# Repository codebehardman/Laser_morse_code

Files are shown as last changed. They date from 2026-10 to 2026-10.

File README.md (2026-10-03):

# Laser Morse Code Transceiver

Firmware for laser transceiver: two identical units that talk
to each other in Morse code over a visible laser beam, without any
radio emissions (so they can be used inside the National Radio Quiet Zone).

Both units run the **same firmware** on an **ESP32-WROOM-32 DevKit**, and
each one can both send and receive. The ESP32's Wi-Fi and Bluetooth are never
switched on by this firmware, so the board does not transmit radio.

(Earlier versions targeted the NUCLEO-F401RE and STM32F103C8T6; see the git
history, e.g. commit `f61c9a8`, if you need them.)

## Modes

When a unit powers up, the on-board LED gives a short blip every half
second while it waits. The **first key press** chooses the mode:

| Press | Mode | LED confirmation |
|---|---|---|
| Tap (< 1 s) | **Morse code** | one long flash |
| Hold ≥ 1 s  | **Serial terminal** | two long flashes (they start while you're still holding, so let go then) |

The serial monitor shows the chosen mode (`===== Mode: ... =====`). Press
**EN** to reset and choose again.

The mode stays until you press reset or cut the power. Set both units to the
same mode.

### Morse code mode
- **Send:** the key turns the laser on while pressed (hand keying, around
  12 words per minute). Text typed in the serial console is keyed out
  automatically at a faster 20 WPM (`/wpm` changes it). Morse is slow:
  roughly 0.6 s per letter at 20 WPM, so the console shows how long each
  message will take.
- Typed messages start with the Morse start-of-message signal `-.-.-` (KA).
  It lets the receiver lock onto the faster typed speed before the first
  letter, and it is not shown as text.
- **Receive:** the LED lights while the laser hits the phototransistor, and
  the pulses are decoded to text in the serial console. The receiver adapts
  to the sender's speed: it compares short and long marks to find the
  dot/dash cutoff, and after a pause it goes back to hand-keying speed.
- Holding the key for more than 1.5 s keeps the laser on for aiming. The
  receiver ignores holds that long, so aiming never shows up as text.

### Serial terminal mode
A text link between two PCs. Type a line and press **Enter**: the whole line
is sent over the laser and appears in the other unit's terminal as
`RX< ...`. It works in both directions at once.
- Each line travels as one frame (start marker, text, CRC-8 checksum, end
  marker). The receiver shows a line only if it arrived intact, and prints
  `[message corrupted - ask to resend]` otherwise.
- The laser link runs at **300 baud, 8 data bits, even parity, 1 stop bit**
  (about 27 characters per second). The design document specifies 9600 baud,
  but the phototransistor with its 100 kΩ pull-up is too slow for that (see
  Hardware notes). A dedicated task
  on the ESP32's second core sends and receives the bits, sampling the
  sensor 8 times per bit with a 3-sample majority vote.
- Backspace works while typing. Commands in this mode:
  - `/baud <n>` changes the link speed on the fly (set the **same** on both
    units).
  - `/rxdebug on|off` shows every received byte in hex, plus error counts.
  - `/level` and `/threshold` work here too. Everything else needs Morse mode.
- Holding the key keeps the laser on for aiming. The other unit sees this as
  a line break and prints nothing.
- The LED flashes when data arrives.

## Repository layout

```
platformio.ini            build environments (firmware + PC unit tests)
include/board_config.hpp  pin assignments and tunable constants
src/
  main.cpp                setup()/loop(): mode selection, then runs the mode
  modes/
    mode_select.{hpp,cpp}   power-up key press: short = Morse, long = serial
    morse_mode.{hpp,cpp}    Morse code mode
    serial_mode.{hpp,cpp}   serial terminal mode
  commands.{hpp,cpp}      serial console commands (/help, /test, /wpm, ...)
  diagnostics.{hpp,cpp}   hardware tests: laser, sensor, button, link
  console.{hpp,cpp}       serial console over the board's USB port
  device.hpp              references to all modules, shared by commands/tests
  drivers/                laser, phototransistor, button, status LED drivers,
                          laser_uart: serial link over the laser (core-0 task)
lib/morse/src/            hardware-independent Morse code library
  morse_code.{hpp,cpp}        ITU alphabet: A-Z, 0-9, punctuation
  morse_transmitter.{hpp,cpp} text -> laser on/off timing (non-blocking)
  morse_decoder.{hpp,cpp}     light timing -> text, adapts to the sender's speed
lib/optical_uart/src/     hardware-independent 8E1 software UART + line framing
test/                     unit tests for both libraries, run on your PC
```

## Wiring

| Part | ESP32 pin | Notes |
|---|---|---|
| Laser (via NPN transistor Q1) | **GPIO 25** | high = laser on |
| Phototransistor + 100 kΩ pull-up | **GPIO 26** | read with the ADC. **Pull-up to 3V3, never 5 V** |
| Key button to GND | **GPIO 27** | internal pull-up |
| Status LED | GPIO 2 (on board) | |
| Laser supply (R1 + laser diode) | **VIN / 5V** | USB 5 V while plugged in |
| Pull-up supply | **3V3** | |
| USB | on-board connector | power, serial console and flashing |

```
ESP32 DevKit
  VIN  ──[100Ω R1]──▶|── laser diode ── Q1 collector
  GPIO25 ──[~1kΩ]──────────────────────── Q1 base   (Q1 emitter → GND)
  3V3  ──[100kΩ]──┬── GPIO26
                  └── phototransistor collector   (emitter → GND)
  GPIO27 ──[button]── GND
```

ESP32 pins are 3.3 V only. Avoid GPIO 0, 2, 12 and 15 (they affect booting)
for external parts. To use different pins, add `-D LMC_PIN_...=` flags in
`platformio.ini`.

## Light threshold (ambient light)

The phototransistor is read with the ADC: **0 = very bright, 4095 = dark**. A
reading below the **threshold** counts as "laser detected". Ambient light
also lowers the reading, so a bright room needs a lower threshold than a
dark one.

**In the code**, set the room type in `include/board_config.hpp`:

```cpp
constexpr Lighting kLighting = Lighting::Dark;   // or Lighting::Bright
constexpr uint16_t kThresholdDarkRoom = 2000;
constexpr uint16_t kThresholdBrightRoom = 700;
```

**At runtime** (both modes, lost on reset):

| Command | Does |
|---|---|
| `/level` | shows the live reading for 5 s, with a bar and LASER/dark |
| `/threshold` | shows the current threshold and reading |
| `/threshold 1500` | sets it to 1500 |
| `/threshold dark` / `bright` | uses the preset from the config |
| `/threshold auto` | measures the room (other laser off), then the other unit's laser (hold its button), and sets the threshold halfway between |

Once you've found a value that works, put it in `board_config.hpp` so it
survives a reset.

## Flashing

Plug the ESP32 into the computer and run:

```sh
pio run -e esp32 -t upload
pio device monitor
```

Or in VS Code: PlatformIO sidebar → **esp32** → **Upload**, then
**Monitor**. The board shows up as `/dev/cu.usbserial-*` on macOS (`COMx` on
Windows). Close any serial monitor on that port first. If the upload stops
at "Connecting...", hold the board's **BOOT** button until the upload starts.
If it fails with "serial noise or corruption", lower `upload_speed` in
`platformio.ini` (e.g. to 115200).

Flash both units the same way.

## Using the serial console

Open the board's USB serial port in any terminal at **115200 baud**. Opening
the port restarts the board, so you'll see the mode prompt. The first line
shows the firmware build time (`firmware build 202610022245` =
2026-10-02 22:45), so you can check both units run the same version. In Morse mode,
each line you type is sent as Morse code when you press Enter. Received text
shows up as `RX< ...`.

```
/help               list commands
/status             settings, receiver state, decoder speed estimate
/wpm <n>            transmit speed, 5-40 words per minute (default 20)
/aim on|off         hold the laser on to align the units
/stop               abort the current transmission
/table              print the Morse alphabet
/level, /threshold  light sensor (see "Light threshold"; also in serial mode)
```

## Hardware tests

### Console tests (Morse mode)

| Command | What it checks |
|---|---|
| `/test laser`  | Blinks the laser 5 times. If you reflect the beam back with a mirror, it also counts the pulses at its own sensor |
| `/test sensor` | Prints every light/dark change for 10 s with timings and ADC levels. Use it to check aim and ambient-light interference |
| `/test button` | Prints key presses for 10 s |
| `/test all` | All of the above |
| `/test edge` then `/test tx 200 1` | **Receiver speed.** Run `/test edge` on the receiving unit, then `/test tx 200 1` on the other (200 pulses of 1 ms). Reports in microseconds how much the phototransistor stretches the pulses, and the highest link speed it can handle |
| `/test rx` then `/test tx` | **Link test across two units.** Run `/test rx` on the receiving unit first, then `/test tx` on the sending unit. The sender transmits 100 pulses of 20 ms. The receiver reports how many arrived and their widths, and gives PASS if the error rate is ≤ 10% (the design requirement) |

The link test is the quick way to run the distance (Test 2, 30 m) and
interference (Test 3, lamp at 1 m) checks from the design document.

## Unit tests (no hardware needed)

```sh
pio test -e native
```

- **Morse:** the alphabet tables, the transmitter's exact timing, and
  transmitter → decoder loopback, including speed mismatch, ±20% human timing
  jitter, switching between typed and hand-keyed speeds, the start prosign,
  aim holds and unknown patterns.
- **Serial link:** frame layout, all 256 byte values, any sampling phase,
  ±3% clock mismatch, detection of a flipped bit, glitches, and a held-on
  laser.
- **Line framing:** CRC, round trips, and that damaged or partial messages
  are always reported, never shown wrong or dropped silently.

## Morse timing

Standard ITU timing based on a unit of `1200 / WPM` ms: dot = 1 unit,
dash = 3, gap between elements = 1, between letters = 3, between words = 7.
The decoder estimates the sender's unit from the incoming marks, so people
keying at different speeds are decoded without any setup. Undecodable
patterns appear as `*`.

## Hardware notes

- **Laser brightness.** The laser circuit is designed for 5 V. Take it from
  the ESP32's VIN/5V pin, which carries USB 5 V while plugged in. From 3.3 V
  the laser gets only about a third of its current; if you must use 3.3 V,
  change R1 from 100 Ω to about 33 Ω (check the laser's datasheet first).
- **Phototransistor pull-up: sensitivity vs. speed.** A larger pull-up is
  more sensitive but slower to return high after the light goes off. With
  100 kΩ the laser is detected, but 9600 baud came through garbled; with
  10 kΩ the laser was no longer detected at all; 1200 baud was still
  corrupted, 300 baud worked. The link therefore runs at 300 baud
  (`config::kLinkBaud`). To go faster, try 50 kΩ (2 × 100 kΩ in parallel) and
  use `/test edge` to find the highest speed it supports.
- **Q1 base resistor.** The design-doc schematic drives the laser
  transistor's base straight from the microcontroller pin. Add a resistor of
  about 1 kΩ.

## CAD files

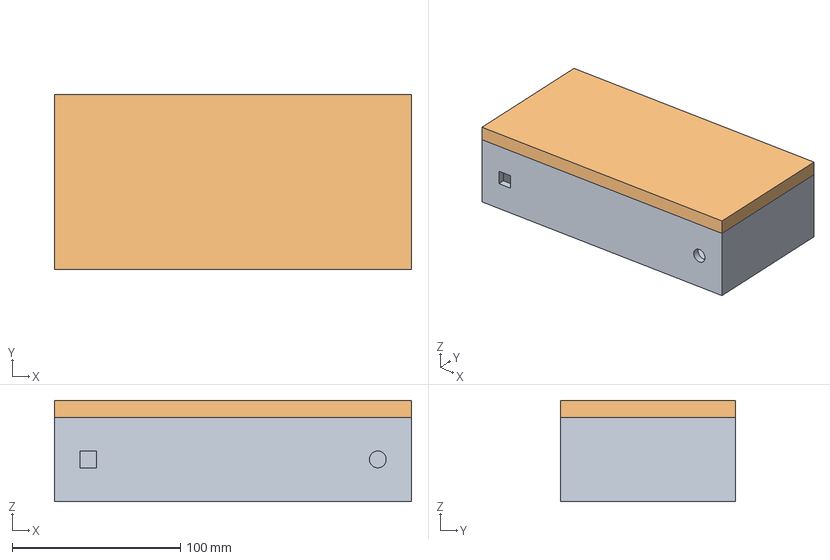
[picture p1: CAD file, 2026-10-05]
box_assembly.step
212.0 x 104.0 x 60.0 mm
box_body
box_lid

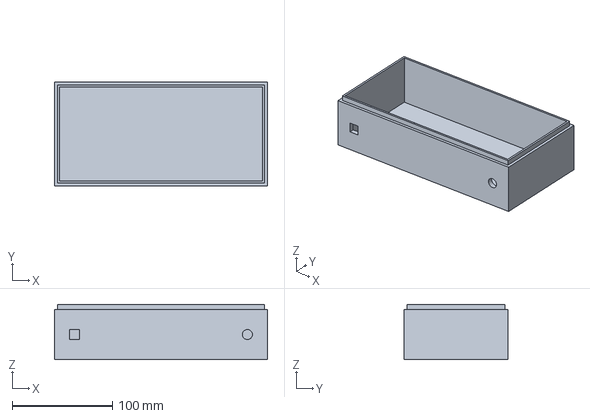
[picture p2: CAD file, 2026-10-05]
box_body.step
212.0 x 104.0 x 55.0 mm

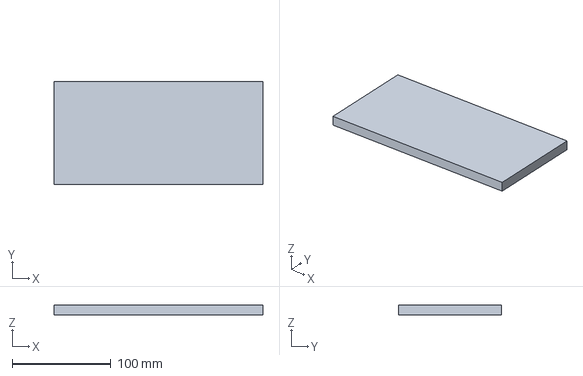
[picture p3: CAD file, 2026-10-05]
box_lid.step
212.0 x 104.0 x 10.0 mm

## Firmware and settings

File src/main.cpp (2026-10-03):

// Laser Morse code transceiver firmware (ESP32-WROOM-32 DevKit).
//
// Both units run this same firmware; each one transmits and receives.
// After power-up the first key press selects the mode:
//
//   Short press  -> Morse code mode (modes/morse_mode.cpp)
//                   The key turns the laser on, the status LED follows the
//                   received light, and received Morse is decoded to text.
//   Hold >= 2 s  -> Serial terminal mode (modes/serial_mode.cpp)
//                   Whatever is typed in one unit's serial terminal appears
//                   in the other's, sent at 9600 baud over the laser.
//
// The mode stays until reset. The serial console is the board's USB port.

#include <Arduino.h>

#include "board_config.hpp"
#include "console.hpp"
#include "device.hpp"
#include "modes/mode_select.hpp"
#include "modes/morse_mode.hpp"
#include "modes/serial_mode.hpp"
#include "morse_code.hpp"

#ifndef LMC_BUILD_ID
#define LMC_BUILD_ID 0  // set by platformio.ini to the build time, YYYYMMDDhhmm
#endif

namespace {

Laser laser(LMC_PIN_LASER);
PhotoSensor sensor(LMC_PIN_SENSOR, config::kSensorDebounceMs, config::kSensorThreshold);
LaserUart link(LMC_PIN_LASER, sensor);
Button button(LMC_PIN_BUTTON, config::kButtonDebounceMs);
StatusLed led(LMC_PIN_STATUS_LED, LMC_STATUS_LED_ACTIVE_LOW);

morse::MorseTransmitter transmitter(morse::wpmToUnitMs(config::kDefaultWpm));
morse::MorseDecoder decoder(morse::wpmToUnitMs(config::kKeyedWpm));

Settings settings{config::kDefaultWpm, /*aim=*/false};
Device device{laser, link, sensor, button, led, transmitter, decoder, settings};

Mode mode = Mode::Morse;

}  // namespace

void setup() {
    laser.begin();
    led.begin();
    sensor.begin();
    button.begin();
    console::begin();

    console::println();
    console::printf("Laser Morse transceiver (firmware build %llu)\n",
                    static_cast<unsigned long long>(LMC_BUILD_ID));
    mode = selectMode(device);

    if (mode == Mode::SerialTerminal) {
        serial_mode::begin(device);
    } else {
        morse_mode::begin(device);
    }
}

void loop() {
    if (mode == Mode::SerialTerminal) {
        serial_mode::update(device);
    } else {
        morse_mode::update(device);
    }
}

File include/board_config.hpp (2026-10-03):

#pragma once

// Pin assignments and tunables for the ESP32-WROOM-32 DevKit transceiver.
//
// Any pin can be overridden from platformio.ini with a build flag,
// e.g. -D LMC_PIN_BUTTON=33. All pins are 3.3 V only: tie the
// phototransistor pull-up to 3.3 V, never 5 V.

#include <Arduino.h>

// Avoids the boot-strapping pins (GPIO 0, 2, 12, 15) for external parts.
#ifndef LMC_PIN_LASER
#define LMC_PIN_LASER 25  // laser via NPN transistor, high = on
#endif
#ifndef LMC_PIN_SENSOR
#define LMC_PIN_SENSOR 26  // phototransistor + pull-up, read with the ADC
#endif
#ifndef LMC_PIN_BUTTON
#define LMC_PIN_BUTTON 27  // key to GND, internal pull-up
#endif
#ifndef LMC_PIN_STATUS_LED
#define LMC_PIN_STATUS_LED 2  // on-board blue LED
#endif
#ifndef LMC_STATUS_LED_ACTIVE_LOW
#define LMC_STATUS_LED_ACTIVE_LOW 0
#endif

namespace config {

// ---------------------------------------------------------------------------
// Light-sensor threshold
//
// The phototransistor is read with the ADC: 0 = very bright ... 4095 = dark.
// A reading BELOW the threshold counts as "laser detected". Ambient light
// pulls the reading down too, so in a bright room the threshold must be
// lower (closer to what only the laser can reach).
//
// Use /level to see the live reading, and /threshold to change it without
// reflashing (/threshold auto measures the room for you). Runtime changes
// are lost on reset; put the value you settle on below.

enum class Lighting { Dark, Bright };

// >>> Change this line to match the room: Lighting::Dark or Lighting::Bright
constexpr Lighting kLighting = Lighting::Dark;

constexpr uint16_t kThresholdDarkRoom = 2000;   // dark room: ambient reads ~4000
constexpr uint16_t kThresholdBrightRoom = 700;  // bright room: ambient reads lower

constexpr uint16_t kSensorThreshold =
    kLighting == Lighting::Dark ? kThresholdDarkRoom : kThresholdBrightRoom;
// ---------------------------------------------------------------------------

// Serial console speed (set the same in your terminal).
constexpr uint32_t kConsoleBaud = 115200;

// Morse speeds (words per minute):
// - typed text is sent fast (changeable with /wpm);
// - the receiver starts from the hand-keying (button) speed and adapts.
//   Typed messages begin with a start signal that tells it their speed.
constexpr uint32_t kDefaultWpm = 20;
constexpr uint32_t kKeyedWpm = 12;
constexpr uint32_t kMinWpm = 5;
constexpr uint32_t kMaxWpm = 40;

// Debounce times.
constexpr uint32_t kButtonDebounceMs = 15;
constexpr uint32_t kSensorDebounceMs = 3;

// Print a newline in the console after this much receive silence.
constexpr uint32_t kMessageEndMs = 3000;

// Mode selection: the first key press after power-up picks the mode.
// Shorter than this = Morse mode, held at least this long = serial terminal.
constexpr uint32_t kModeSelectHoldMs = 1000;

// Serial terminal mode: laser link speed (8E1 framing). The design doc asks
// for 9600, but the phototransistor with its 100k pull-up is too slow for
// that: 300 baud was the speed that worked in testing (~27 characters per
// second, so a short line takes about a second). Try faster with /baud, or
// measure with /test edge.
constexpr uint32_t kLinkBaud = 300;

// Serial terminal mode: show what you type in your own terminal too, since
// most terminals don't echo locally.
constexpr bool kSerialLocalEcho = true;

}  // namespace config

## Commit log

2026-10-02 Add laser Morse transceiver firmware for NUCLEO-F401RE
    - Same firmware on both units: button keys the laser, receiver drives
    buzzer/LED and decodes Morse with adaptive speed tracking
    - Hardware-independent Morse library (ITU alphabet, non-blocking
    transmitter, decoder) with native Unity tests
    - Hardware diagnostics: laser, sensor, button, buzzer, two-unit link test
    - standalone (schematic pins) and usb_serial PlatformIO environments
    [board_config.hpp, console.cpp]
2026-10-02 Add power-up mode selection and serial terminal mode
    The first key press after power-up selects the mode: a short press enters
    Morse code mode, holding for 2 s enters serial terminal mode. Serial
    terminal mode is a transparent link between two terminals at 9600 baud
    8E1 over the laser, bit-banged from a TIM2 interrupt with 8x
    oversampling and majority voting; bytes failing parity/framing are
    dropped. The framing logic lives in lib/optical_uart with native tests.
    In the standalone build (no USB serial) a long press runs the hardware
    self-test, replacing the old hold-key-at-reset gesture.
    [board_config.hpp, console.cpp, laser_uart.cpp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]
2026-10-02 Remove the buzzer; use the on-board LED for all local feedback
    The hardware has no buzzer. LD2 now shows received light, the mode
    selection (blips while waiting, one long flash for Morse, two for serial
    terminal) and standalone self-test progress. Removes the buzzer driver,
    /sidetone, /test buzzer and the serial-mode parity chirp. The usb_serial
    build now only needs the button moved from PA2 to PA4.
    [board_config.hpp, main.cpp]
2026-10-02 Port firmware from NUCLEO-F401RE to STM32F103C8T6
    - Build for bluepill_f103c8 with the console on the chip's native USB
    (CDC), which removes the PA2/PA3 conflict: one build, button on PA2
    - Status LED on PC13, active low
    - Upload via ST-LINK V2 (SWD, clone-chip ID accepted) or a USB-serial
    adapter through the ROM bootloader (bluepill_uart)
    - Drop the console-less standalone build and its LED self-test
    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
2026-10-03 Add ESP32-WROOM-32 support and make it the default board
    - New esp32 PlatformIO environment (flashes over the board's USB)
    - Per-platform pin defaults in board_config.hpp: laser GPIO 25,
    phototransistor GPIO 26, button GPIO 27, LED GPIO 2
    - LaserUart timer interrupt and fast pin access for ESP32 and STM32
    - upload_speed 460800: 921600 corrupted on the CH340 adapter
    - README: ESP32 wiring and flashing
2026-10-03 Send serial terminal text a line at a time with a CRC
    Typed characters are collected locally (with backspace) and sent on
    Enter as one STX/text/CRC-8/ETX frame. The receiver prints a line only
    if it arrived intact and shows "[message corrupted]" otherwise, instead
    of printing garbled bytes. Framing lives in lib/optical_uart with
    native tests.
2026-10-03 Report serial messages whose start and end markers were both lost
    Stray bytes received outside a frame are now tracked, so a message that
    lost both STX and ETX is reported as corrupted after the timeout instead
    of disappearing silently.
2026-10-03 Shorten mode hold to 1 s, speed up Morse, run the laser link at 1200 baud
    - Mode select: tap = Morse, hold 1 s = serial terminal; clearer prompt
    and a visible "===== Mode: ... =====" banner
    - Default Morse speed 20 WPM (max 40); the console shows the estimated
    send time for each line (morse::messageUnits)
    - Laser link 1200 baud: the 100k phototransistor pull-up is too slow for
    9600 and 10k no longer detects the laser
    - Serial mode: lines starting with '/' print a hint instead of being sent
    [board_config.hpp, test_main.cpp]
2026-10-03 Read the phototransistor with the ADC and a configurable light threshold
    - PhotoSensor reads the ADC (0 bright .. 4095 dark); below the threshold
    = laser. config::kLighting selects the dark-room or bright-room preset
    - /level, /threshold [n|dark|bright|auto] in both modes; auto measures
    the room and the other laser and sets the threshold halfway between
    - The serial link samples from a task on core 0 (ADC reads aren't
    allowed in interrupts) instead of a timer interrupt
    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
2026-10-03 Add receiver speed test, runtime link speed and receive debugging
    - /test edge measures (in us) how much the phototransistor stretches
    1 ms pulses from '/test tx 200 1' and recommends a link speed
    - Serial mode: /baud <n> changes the link speed while running,
    /rxdebug on|off shows received bytes in hex with error counts
    - Startup banner shows the build time (LMC_BUILD_ID)
    [laser_uart.cpp, main.cpp]
2026-10-03 Decode hand-keyed and typed Morse at their own speeds; link at 300 baud
    - Decoder: dot/dash cutoff from the contrast between recent short and
    long marks, letters classified once complete, and back to hand-keying
    speed (12 WPM) after a pause. Fixes slow button keying being read as
    dashes after the typed speed went to 20 WPM
    - Typed messages start with the KA prosign (-.-.-) so the receiver locks
    onto their speed first; the decoder swallows it
    - Serial terminal mode defaults to 300 baud, the speed that worked
    [board_config.hpp, main.cpp, test_main.cpp]
2026-10-03 Add files via upload
    Electrical schematic of the laser transceiver
    [Laser_Transceiver_Schematic.kicad_sch]
2026-10-05 Add files via upload
    3D-printed casing for laser transceiver
    [box_assembly.step, box_body.step, box_lid.step]
2026-10-05 Add files via upload
    Quick demo of the prototype for morse code mode and serial terminal mode
